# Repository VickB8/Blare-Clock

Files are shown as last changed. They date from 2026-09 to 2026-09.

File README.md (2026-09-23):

# BLARE CLOCK

A Small custom desk clock powered by a XIAO ESP32-C3 with a color display and Wi-Fi time sync.

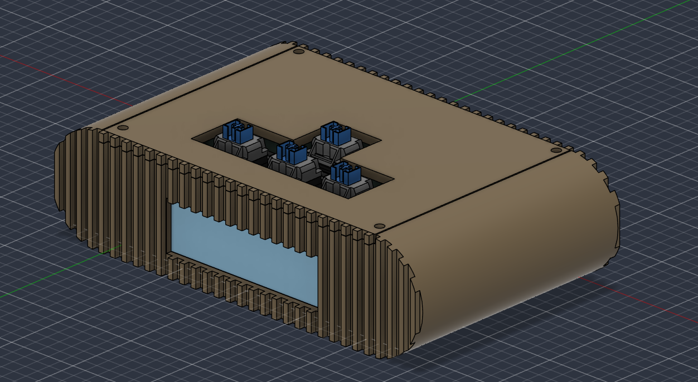
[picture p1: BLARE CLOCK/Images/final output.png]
image alt


# Inspiration

I wanted to make a small desk clock that was more interesting than a normal digital clock I decided to design the PCB, Case and firmware myself use an ESP32-C3 so the clock could connect to Wifi and automatically keep the synchronisation.
I also wanted the final clock to look like an actual finished product instead of just a developement board connected to a display.

# How it Works

The clock uses a Seeed Studio XIAO ESP32-C3 as the main microcontroller. When it starts up, it connects to Wi-Fi and gets the current time using NTP.

The time is then displayed on the display.

The electronics are mounted inside a custom 3D-printed case that I designed specifically for the PCB and display.

# Challenges

One of the biggest challenges was getting the display and XIAO ESP32-C3 working together. I had to figure out the correct pins and how to control the display.

I also had some problems with the KiCad libraries and footprints for the XIAO ESP32-C3. Getting the PCB and its 3D models to show correctly took some troubleshooting.

Another challenge was designing the case. I originally made the display opening too small and didn't leave enough room for the display wires and USB connection. I had to go back and modify the case so the display could actually be connected and the USB port could be accessed.

# What I Learned

How to design a PCB in KiCad
How to work with custom footprints and libraries
How to use an ESP32-C3 with Wi-Fi
How NTP time synchronization works
How to design a 3D-printed enclosure around electronics
How to troubleshoot PCB and 3D-model issues

# Components 

Seeed Studio XIAO ESP32-C3
TFT display
Custom PCB
Connecting wires
3D-printed enclosure
MX style keyboard switches
white blank dsa caps
3.3v piezo buzzer
M3x5x4 heat inserts M3x8mm screws

# Software

Arduino IDE
ESP32 Arduino Core
Adafruit GFX Library
Adafruit ST7789 Library
SPI
WiFi
Time / NTP

# Features

Wi-Fi time synchronization
NTP-based accurate time
Color display

# Design Files

PCB

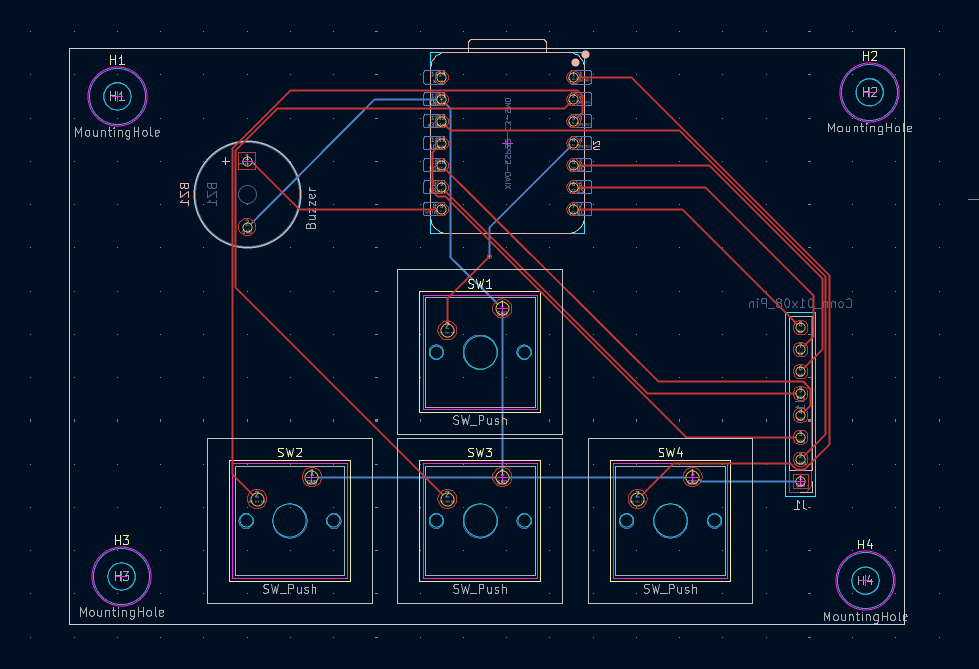
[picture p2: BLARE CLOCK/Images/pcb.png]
image alt


The PCB was designed in KiCad and contains the connections between the XIAO ESP32-C3 and the display.

Schematic

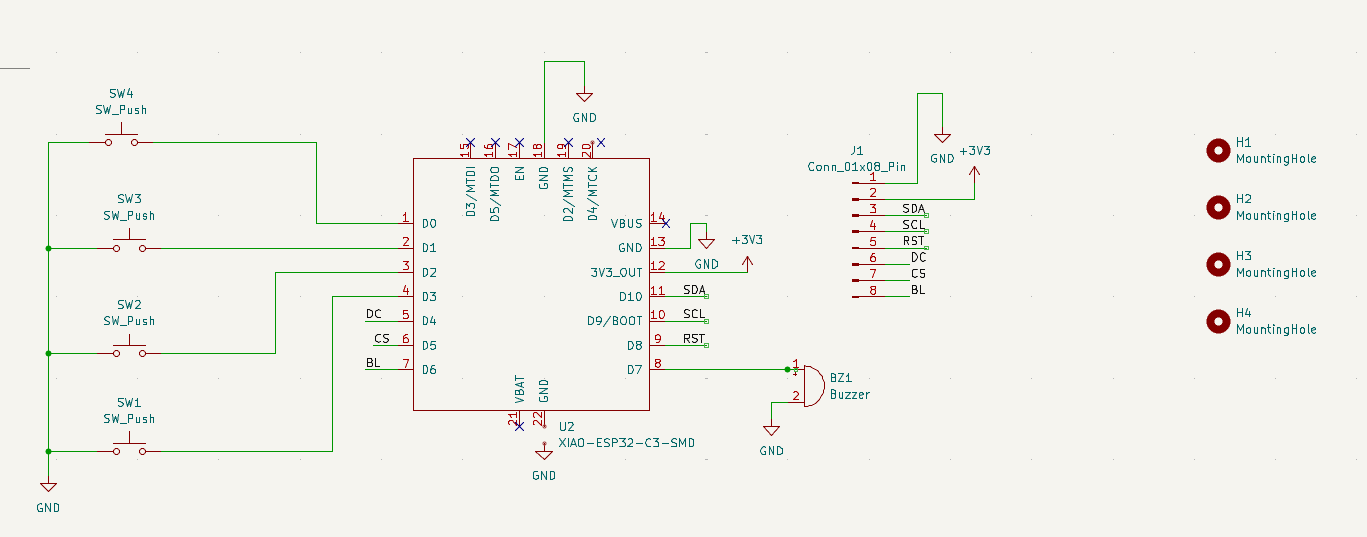
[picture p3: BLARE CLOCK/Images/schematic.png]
image alt


Case

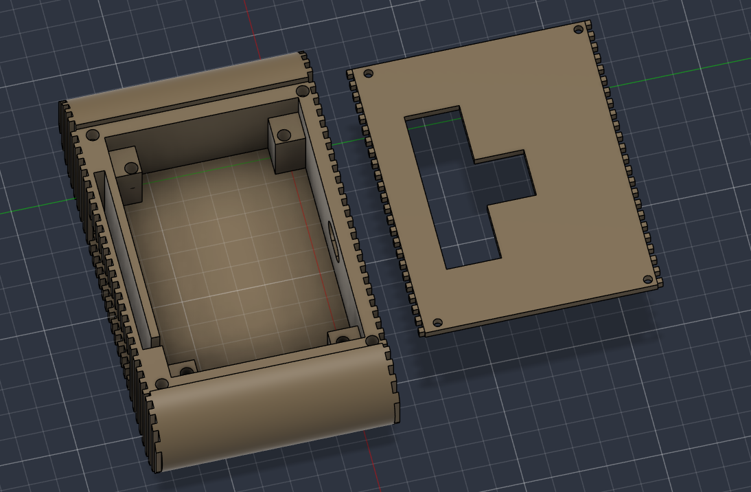
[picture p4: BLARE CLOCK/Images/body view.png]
image alt


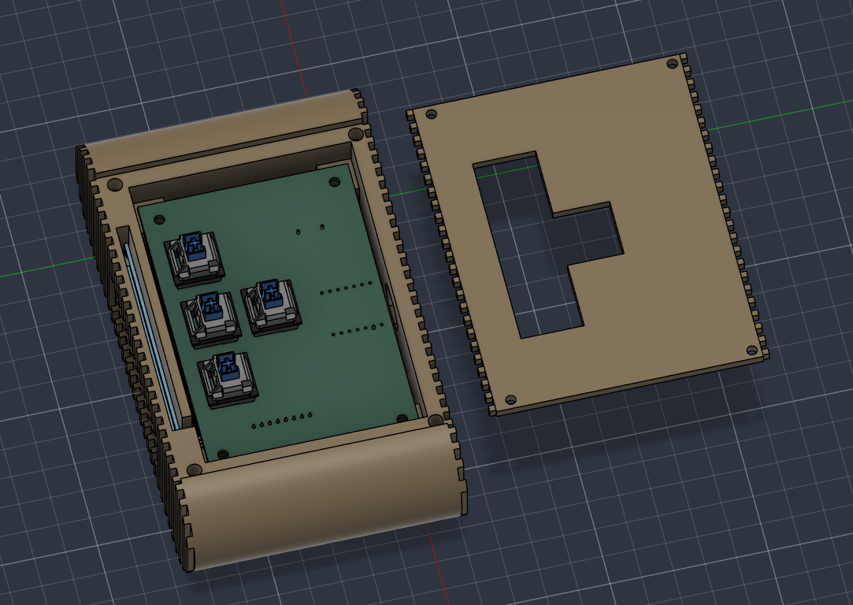
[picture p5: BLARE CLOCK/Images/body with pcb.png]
image alt


The enclosure was designed to hold the electronics while leaving access for the display and USB port.

Firmware

The firmware is written in Arduino/C++ and handles Wi-Fi connection, NTP time synchronization, and drawing the clock interface on the display.

Final Result

This project helped me learn more about PCB design, embedded programming, displays, and designing physical enclosures for electronics. I started with the individual components and gradually worked toward making the complete clock.

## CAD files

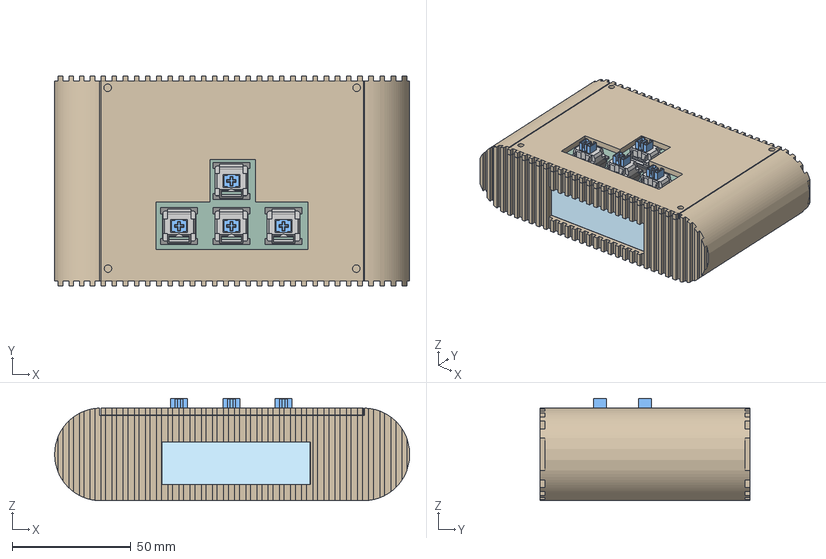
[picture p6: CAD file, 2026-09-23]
BLARE CLOCK/Cad/clock design.step
149.6 x 88.4 x 43.1 mm
pcd374_PCB
BOSS-EXTRUDE14_8_
BOSS-EXTRUDE7_4_
BOSS-EXTRUDE7_3_
BOSS-EXTRUDE14_4_
BOSS-EXTRUDE14_2_
BOSS-EXTRUDE14_11_
BOSS-EXTRUDE7_7_
BOSS-EXTRUDE14_9_
BOSS-EXTRUDE14_3_
BOSS-EXTRUDE14_7_
MIRROR2
BOSS-EXTRUDE14_5_
BOSS-EXTRUDE14_12_
BOSS-EXTRUDE7_8_
BOSS-EXTRUDE7_1_
BOSS-EXTRUDE14_10_
BOSS-EXTRUDE7_9_
BOSS-EXTRUDE14_6_
BOSS-EXTRUDE14_1_
BOSS-EXTRUDE7_6_
BOSS-EXTRUDE7_2_
CUT-EXTRUDE5
BOSS-EXTRUDE7_5_
U.FL Connector v1
Button (1) x 2
Shield
Button x 4
Pins x 4
8 pin header v1_1
8 pin header v1_1_1
8 pin header v1_1_2
8 pin header v1_1_3
8 pin header v1_1_4
8 pin header v1_1_5
8 pin header v1_1_6
8 pin header v1_1_7
8 pin header v1_1_8
Buzzer_12x95RM76
PinSocket_1x08_P2.54mm_Vertical_1
pcd clock_PCB

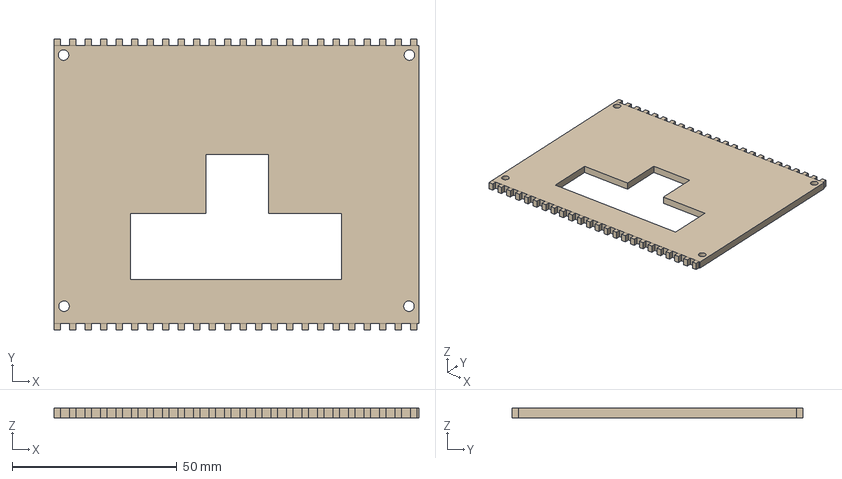
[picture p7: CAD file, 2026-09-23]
BLARE CLOCK/Production/Final Top.step
110.7 x 88.4 x 3.00 mm

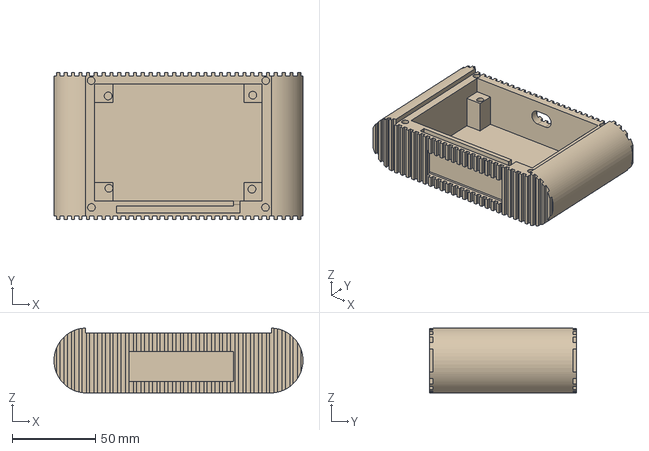
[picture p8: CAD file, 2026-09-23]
BLARE CLOCK/Production/Final Body Clock.step
149.7 x 88.4 x 39.0 mm

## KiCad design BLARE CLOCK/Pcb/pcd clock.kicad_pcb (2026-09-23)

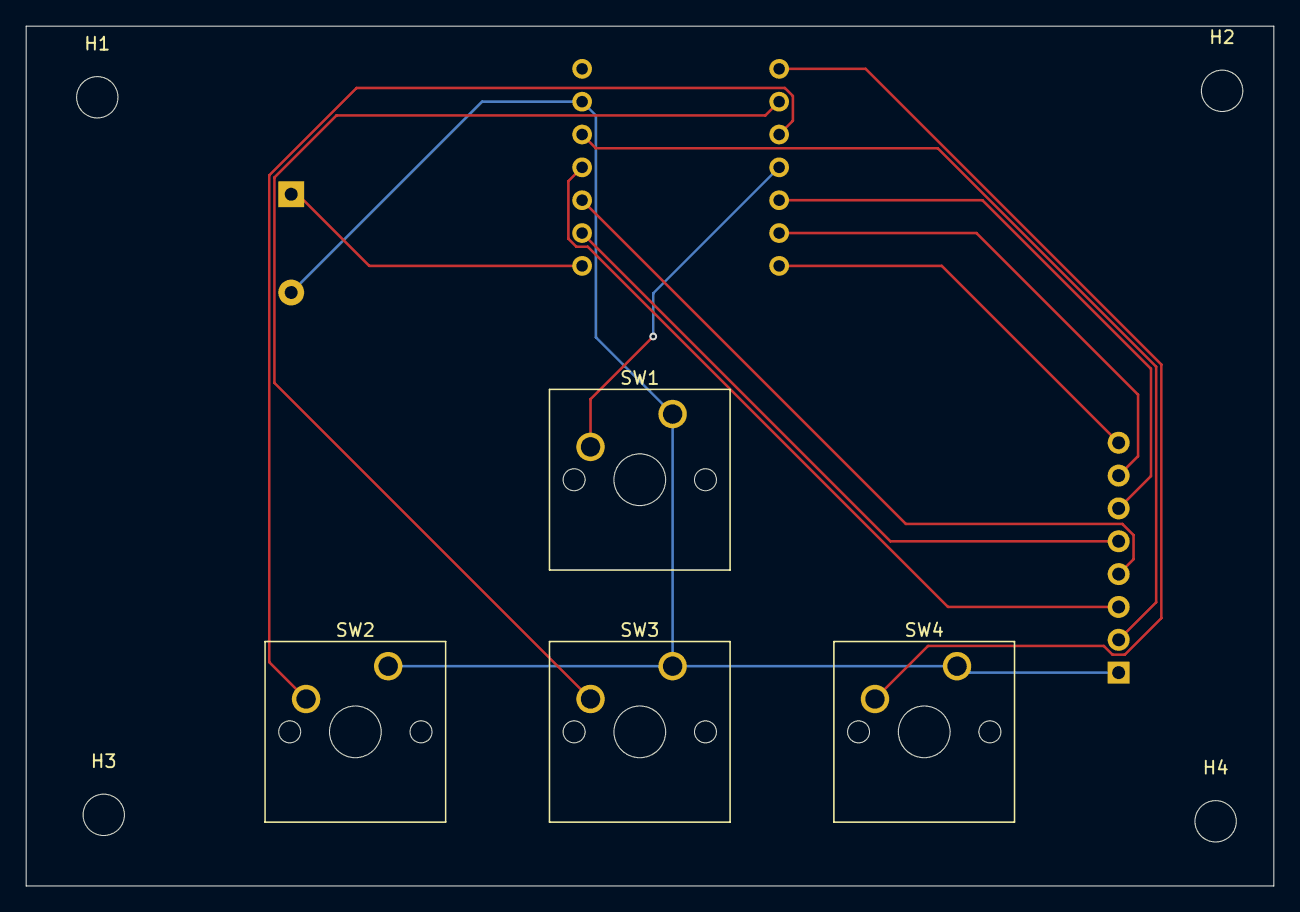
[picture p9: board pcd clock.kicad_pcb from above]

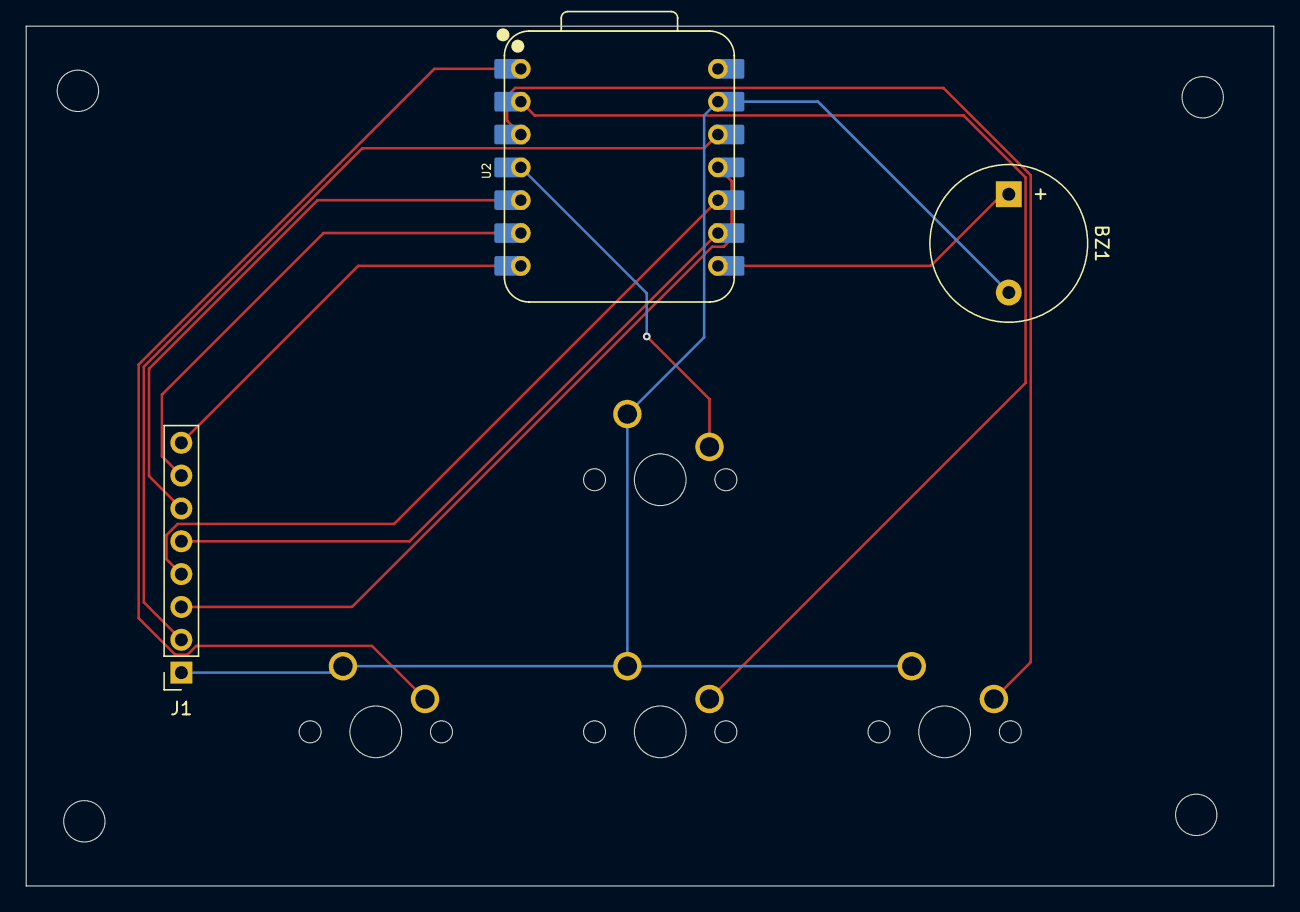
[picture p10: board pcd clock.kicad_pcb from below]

Board: 2 copper layers, 96.5 x 66.5 mm, 11 parts (3 on the bottom side), 13 nets.

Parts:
BZ1: Buzzer; Buzzer_12x9.5RM7.6
H1, H2, H3, H4: MountingHole; MountingHole_3.2mm_M3
J1: Conn_01x08_Pin; PinSocket_1x08_P2.54mm_Vertical
SW1, SW2, SW3, SW4: SW_Push; SW_Cherry_MX_1.00u_PCB
U2: XIAO-ESP32-C3-SMD; XIAO-ESP32-C3-DIP

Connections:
+3V3: J1.2, U2.12 (3V3_OUT)
/BL: J1.8, U2.7 (D6)
/CS: J1.7, U2.6 (D5)
/DC: J1.6, U2.5 (D4)
/RST: J1.5, U2.9 (D8)
/SCL: J1.4, U2.10 (D9/BOOT)
/SDA: J1.3, U2.11 (D10)
GND: BZ1.2 (-), J1.1, SW1.1, SW2.1, SW3.1, SW4.1, U2.13 (GND)
unnamed: BZ1.1 (+), U2.8 (D7)
unnamed: SW4.2, U2.1 (D0)
unnamed: SW3.2, U2.2 (D1)
unnamed: SW2.2, U2.3 (D2)
unnamed: SW1.2, U2.4 (D3)

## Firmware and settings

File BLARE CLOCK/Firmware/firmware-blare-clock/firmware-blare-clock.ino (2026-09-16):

#include <Adafruit_GFX.h>
#include <Adafruit_ST7789.h>
#include <SPI.h>
#include <WiFi.h>
#include "time.h"

const char* ssid     = "Jaiguruji77";
const char* password = "my password privacy";

const char* ntpServer = "pool.ntp.org";
const char* timeZone  = "EST5EDT,M3.2.0,M11.1.0";

#define VIV_SCLK 9
#define VIV_MOSI 10
#define VIV_RST 8
#define VIV_DC 4
#define VIV_CS 5
#define VIV_BL 6

class MyST7789 : public Adafruit_ST7789 {
  public:
  MyST7789(int8_t cs, int8_t dc, int8_t mosi, int8_t sclk, int8_t rst)
  : Adafruit_ST7789(cs, dc, mosi, sclk, rst) {}

  void setOffsets(uint8_t col, uint8_t row ) {
    _colstart = _colstart2 = col;
    _rowstart = _rowstart2 = row;
  }
};

MyST7789 viv(VIV_CS, VIV_DC, VIV_MOSI, VIV_SCLK, VIV_RST);

void setup() {
  Serial.begin(115200);

  pinMode(VIV_BL, OUTPUT);
  digitalWrite(VIV_BL, LOW);

  viv.init(76, 284);
  viv.setOffsets(82, 18);
  viv.invertDisplay(false);
  viv.setRotation(1);

  viv.fillScreen(ST77XX_BLACK);

  viv.setTextColor(ST77XX_WHITE);
  viv.setTextSize(2);
  viv.setCursor(10, 30);
  viv.print("Connected WiF.i.");

  WiFi.begin(ssid, password);
  while (WiFi.status()!= WL_CONNECTED) {
    delay(500);
    Serial.print(".");
  }

  Serial.println("\nWifi connected!");
  Serial.println("TFT Initialized!");

  viv.fillScreen(ST77XX_BLACK);

}

void loop() {
  
  struct tm timeinfo;
  if(!getLocalTime(&timeinfo)){
    Serial.println("Failed to obtain time");
    delay(500);
    return;
  }

  char timeHour[3];
  char timeMinute[3];
  char timeSecond[3];
  char dateStr[11];

  strftime(timeHour, 3, "%H", &timeinfo);
  strftime(timeMinute, 3, "%M", &timeinfo);
  strftime(timeSecond, 3, "%S", &timeinfo);
  strftime(dateStr, 11, "%Y-%m-%d", &timeinfo);

  viv.fillScreen(ST77XX_BLACK);

  viv.setTextSize(4);
  viv.setTextColor(ST77XX_WHITE);
  viv.setCursor(15, 15);
  viv.print(timeHour);
  viv.print(":");
  viv.print(timeSecond);

  viv.setTextSize(1);
  viv.setTextColor(ST77XX_CYAN);
  viv.setCursor(15, 60);
  viv.print(dateStr);

  delay(1000);

}

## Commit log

2026-09-16 Initial commit with all project files
    [Final Body Clock.step, Final Top.step, clock.kicad_pcb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]
2026-09-23 Create CAD
